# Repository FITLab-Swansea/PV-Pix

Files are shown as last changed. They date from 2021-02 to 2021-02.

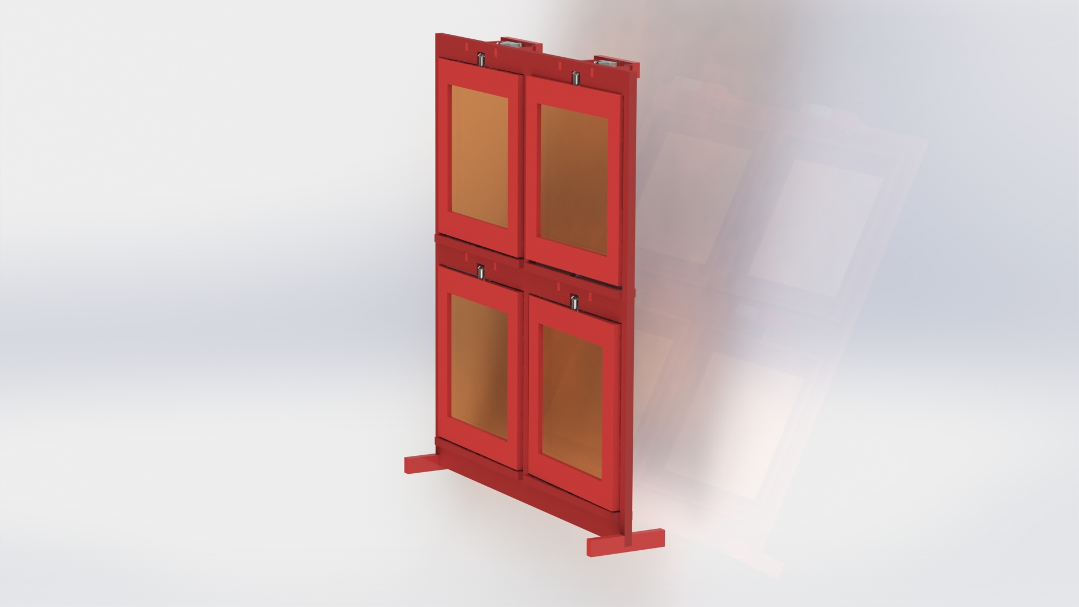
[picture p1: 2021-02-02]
CAD design/Tilttile Prototype/2x2 tilttile close.JPG

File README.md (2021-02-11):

# PV-Pix:
PV-Pix is a slum community co-design of self-powered deformable smart messaging materials for inter-home connections. Each PV-Pix element consists of a deformable energy harvesting material that, when actuated by a person in one home, changes its physical state both there and in a connected home. PV-Pix includes two forms of prototypes one uses rigid materials (TiltTile) and the other flexible ones (FabricOn). 

See the [toolkit website](https://deliot.me/toolkit.html) and [research project website](https://deliot.me) for more details and related work.

## Getting Started
By using the following step-by-step process you can build your own PV-Pix or you can reproduce our work. 

*Dye Sensitised Solar Cell (DSSC) fabrication

*Hardware design

*CAD design

*Bill of materials

*Software code

## License

This project is licensed under the MIT License - see the [LICENSE](LICENSE) and file for details.

The PV-Pix fabrication guide, electronics, prototype designs, MSP430FR5969 Ultra-Low-Power Microcontroller code, Arduino code are all released. 

## Acknowledgments

* FitLab
* Specific
* Swansea University
* EPSRC

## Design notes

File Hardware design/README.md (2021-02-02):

# PV-Pix 

*Hardware design 

It includes block diagram and servo modification process.  

Servo motor modification steps: 

1) Modify SG90 servo motor for continuous rotation. 

2) Remove gear that drives potentiometer.

3) Snip off a few mm of drive shaft. 

4) Trim off lugs. 

5) Set potentiometer to neutral position.

6) Reassemble. 

7) Test.

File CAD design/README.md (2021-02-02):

# PV-Pix 

*CAD design 

Here you can find all designs of both FabricOn and Tilttile prototypes. SolidWorks is used to create solid modeling computer-aided design (CAD). This folder includes both CAD files and images of both prototypes.

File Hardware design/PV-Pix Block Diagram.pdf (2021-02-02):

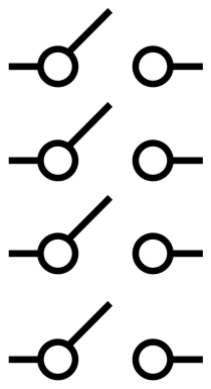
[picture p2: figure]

### MSP430F5529

### SERVO 1

### SERVO 2

### SERVO 3

### SERVO 4

### XBee S1

P2_6

P2_3

P1_6

P2_7

SW1

SW2

SW3

SW4

P8_1

P3_4

P3_3

TX

RX

En

# Transmitting 2x2 PV-Pix

P2_5 | P2_4
P1_5 | P1_4

P1_4

P1_5

P2_4

P2_5

### MSP430F5529

### SERVO 1

### SERVO 2

### SERVO 3

### SERVO 4

### XBee S1

P2_7

P3_4

P3_3

TX

RX

En

# Receiving 2x2 PV-Pix

P2_5 | P2_4
P1_5 | P1_4

P2_0

P1_5

P2_4

P2_5

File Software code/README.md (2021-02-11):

# PV-Pix 

*Software code: 
To create working prototypes use code scripts.

To make a working demo of TiltTile: 
Download the code script of TiltTile_2x2_RX.ino (Receive) and TiltTile_2x2_TX.ino (Transmit).
Upload this code script to microcontroller.
Create a demonstrator as seen in the PV-Pix video (https://deliot.me/toolkit.html)

To make a working demo of FabricOn: 
Download the code script of FabricOn.ino.
Upload this code script to microcontroller.
Create a demonstrator as seen in the PV-Pix video (https://deliot.me/toolkit.html)

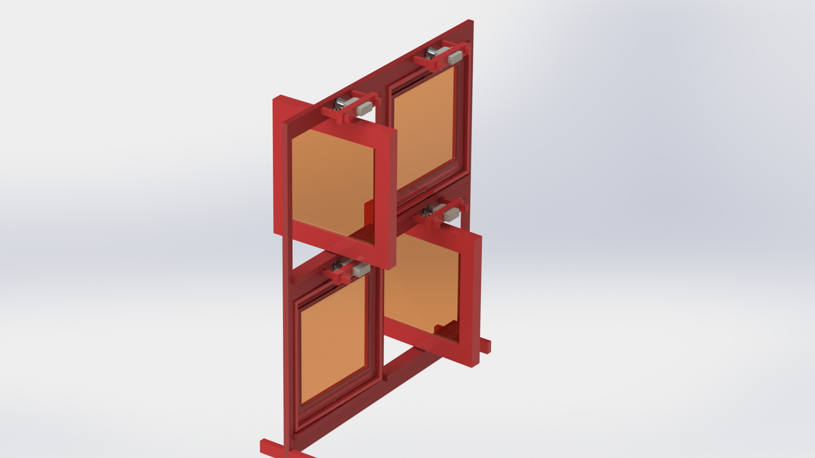
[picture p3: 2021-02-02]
CAD design/Tilttile Prototype/2x2 tilttile open.JPG

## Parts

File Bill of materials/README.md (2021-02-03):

# PV-Pix 

*bill of materials 

BoM document inlcudes parts, their quantity and suppliers for fabrication and construction of prototypes.

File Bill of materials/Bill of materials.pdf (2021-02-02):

PV-Pix was designed by: | and funded by:

PV-Pix: bill of materials

Parts for DSSC Fabrication

Part | Quantity | Supplier
RS PRO 16 Teeth Mitre Gear, 0.5mm Pitch, 20° Angle, 3mm Bore RS Stock No. 182-7986 | 16 | RS Components
Hitec HS40 Servo | 8 | modelshopleeds.co.uk
3mmPlain Miniature Ball Bearing 10mm O.D 618-9884 | 8 | RS Components
Burgundy acrylic 5 mm thick & 3 mm thick | - sheetplastics.co.uk
MSP-EXP430F5529LP | 2 | Digikey

Parts for PVPix Construction

Part | Quantity | Supplier
SG90 Servo motor | 1 | PI Hut
Burgundy acrylic 5 mm thick & 3 mm thick | - sheetplastics.co.uk
Arduino UNO | 1 | PI Hut
OPV Tape | 1 | infinitypv.com

Parts for FabricOn Construction

Part | Quantity | Supplier
FTO glass TEC 15A 2.1 mm x 30 mm x 30 mm | 3 | XOP FÍSICA SL
Ti Nanooxide T/SP | 50 g | Solaronix
Platisol T | 20 ml | Solaronix
Iodolyte Z-50 | 20 ml | Solaronix
Meltonix 1170-60 | 30 cm x 20 cm | Solaronix
Screen MCI 245 mesh 43-80, 45 deg, 13m EXP | 1 | MCI Precision Screen

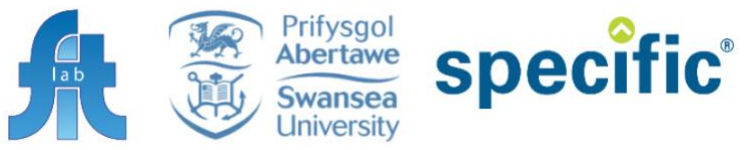
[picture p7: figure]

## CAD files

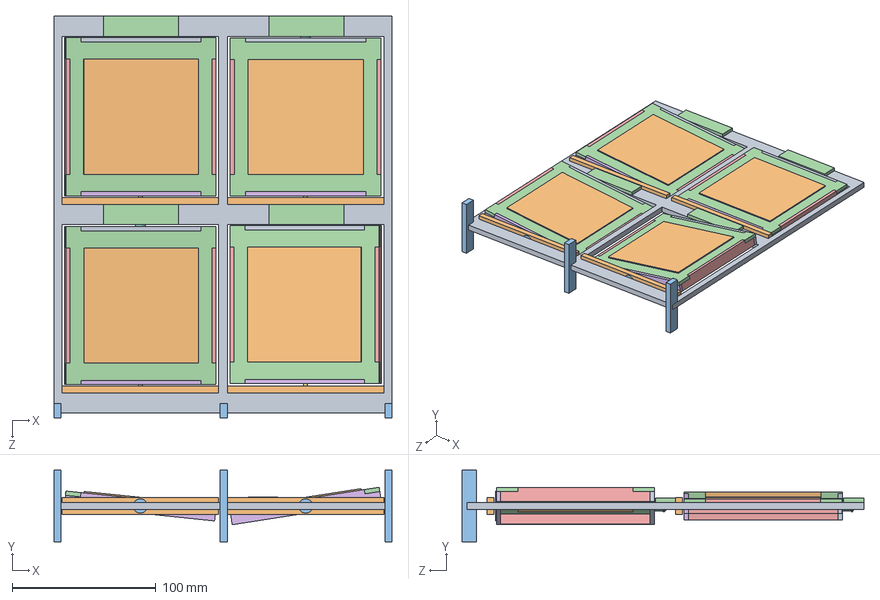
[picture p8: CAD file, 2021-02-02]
CAD design/Tilttile Prototype/Assembly_of_2x2.SLDASM
235.0 x 50.0 x 279.2 mm
Outer_Frame
Bearing_Holder2x2 x 4
Bearign x 4
LeftMount x 4
Side_Frame x 8
Top_and_Bottom_Frame x 4
Dowel x 8
straight bevel pinion_iso x 4
Top_with_hole x 4
Coloured_Glass x 4
Legs x 3
cover x 4

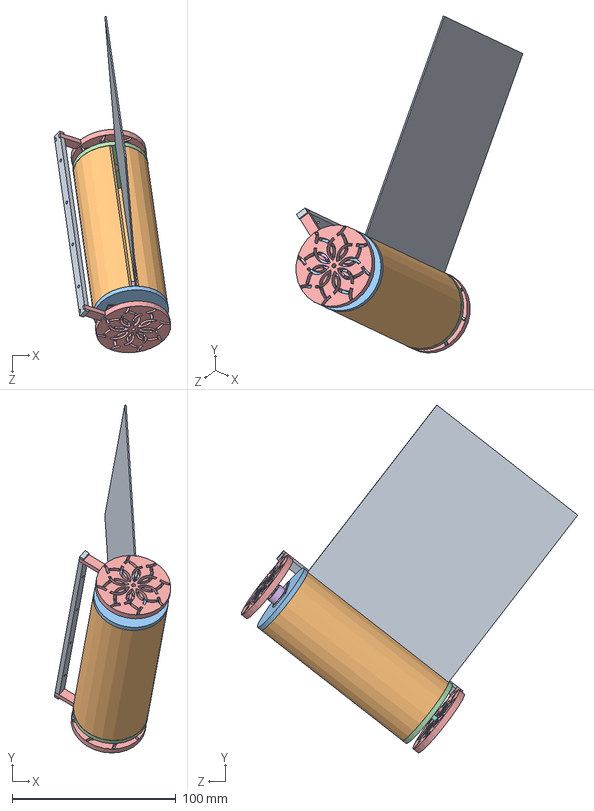
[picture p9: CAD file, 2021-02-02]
CAD design/FabricOn Prototype/Assem_Of_Prototype1.SLDASM
71.2 x 212.7 x 205.7 mm
Back_Plate
Hollow_Roller
Hollow_Roller_Servo_Side
Bearing_Hollow
Final_Bearing_Side x 2
sg90
Fat_Bearing
Dowel

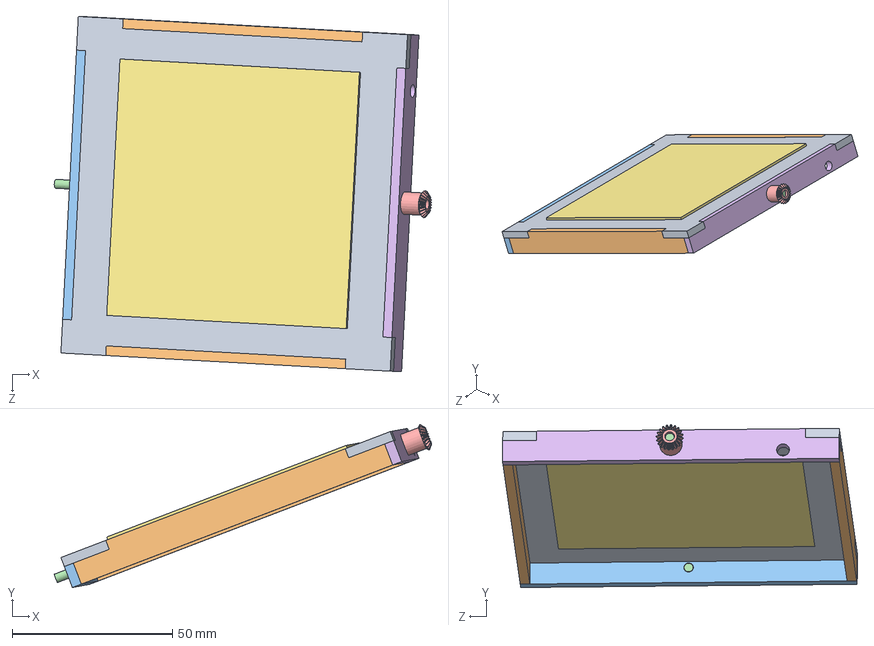
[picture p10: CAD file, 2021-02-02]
CAD design/Tilttile Prototype/Frame_And_Tile.SLDASM
117.6 x 50.8 x 110.6 mm
LeftMount
Side_Frame x 2
Top_and_Bottom_Frame
Dowel x 2
straight bevel pinion_iso
Top_with_hole
Coloured_Glass

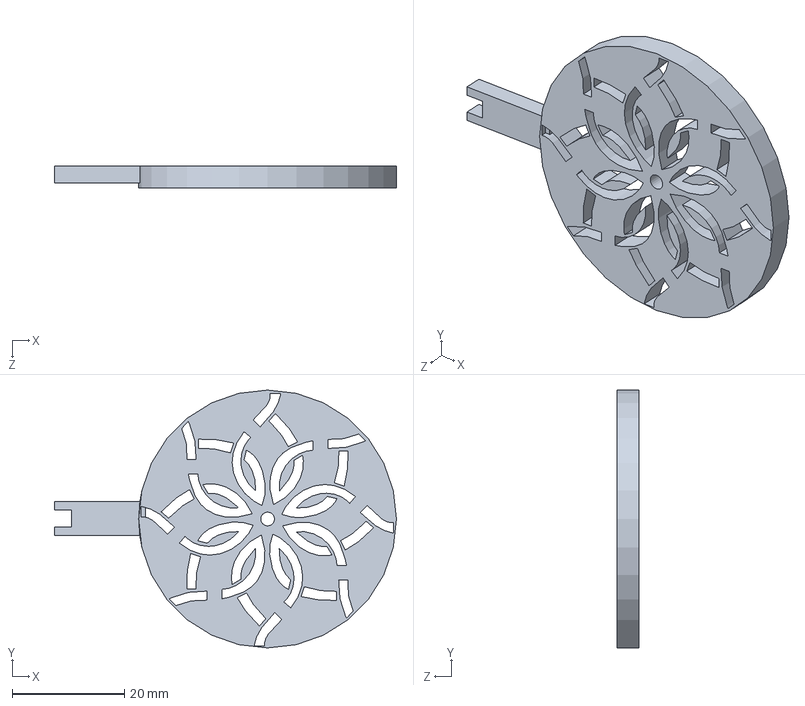
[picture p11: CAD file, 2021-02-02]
CAD design/FabricOn Prototype/Final_Bearing_Side.SLDPRT
61.0 x 46.0 x 3.94 mm

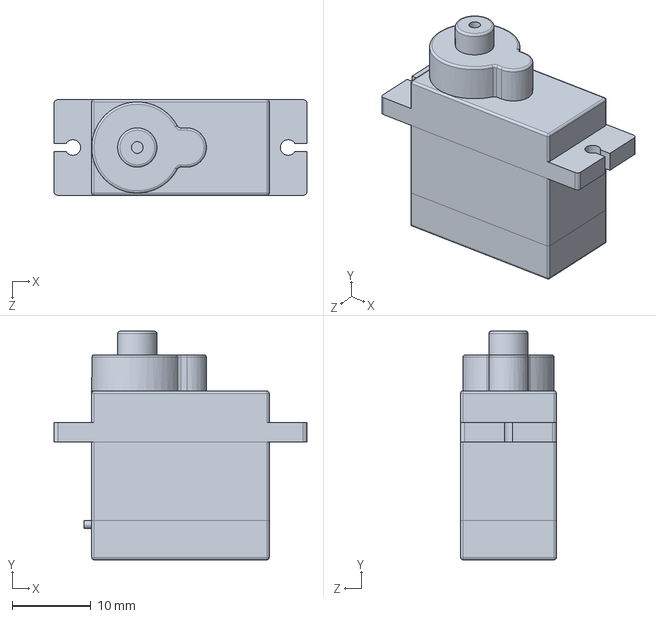
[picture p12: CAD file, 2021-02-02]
CAD design/FabricOn Prototype/sg90.SLDPRT
32.2 x 29.1 x 12.2 mm

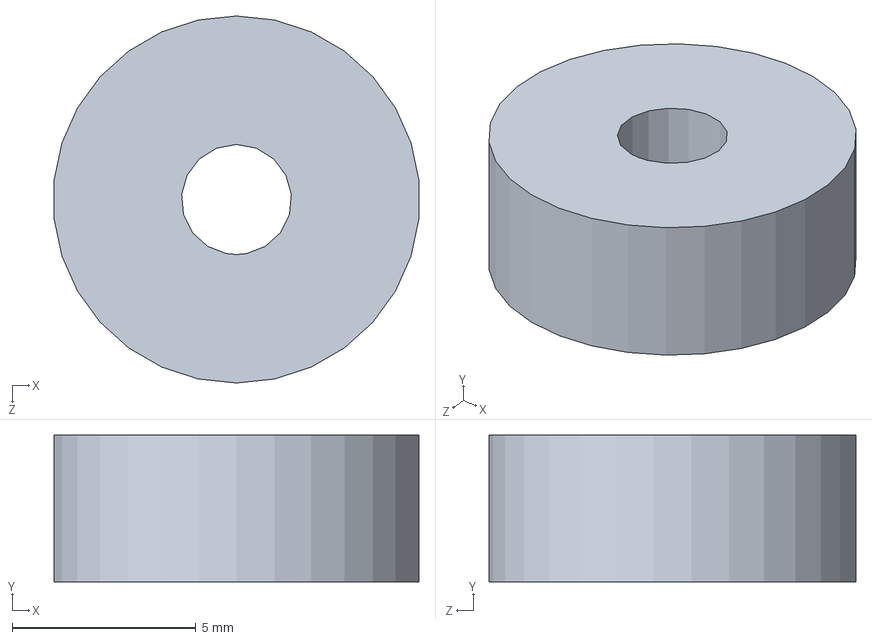
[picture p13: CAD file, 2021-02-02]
CAD design/Tilttile Prototype/Bearign.SLDPRT
9.95 x 4.00 x 10.0 mm

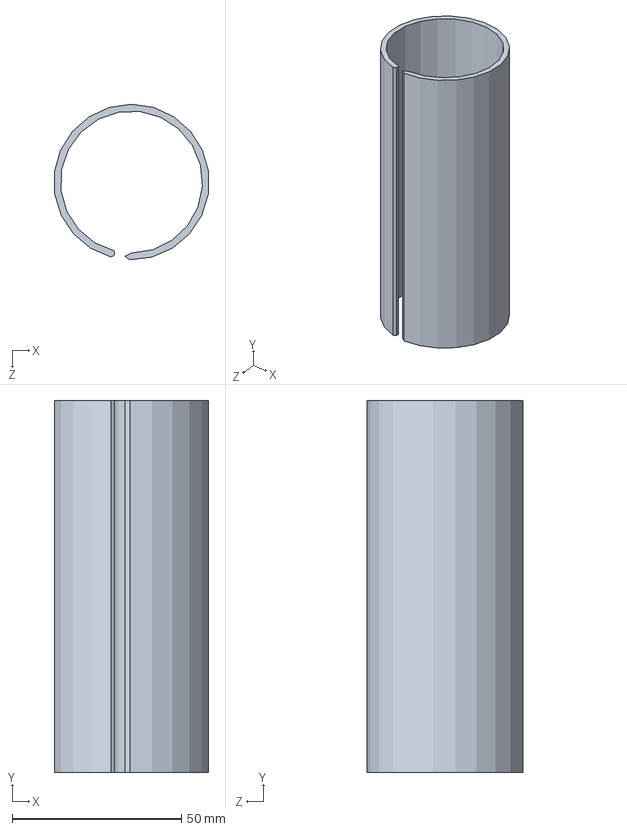
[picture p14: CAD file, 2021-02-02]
CAD design/FabricOn Prototype/Hollow_Roller.SLDPRT
45.6 x 110.0 x 46.0 mm

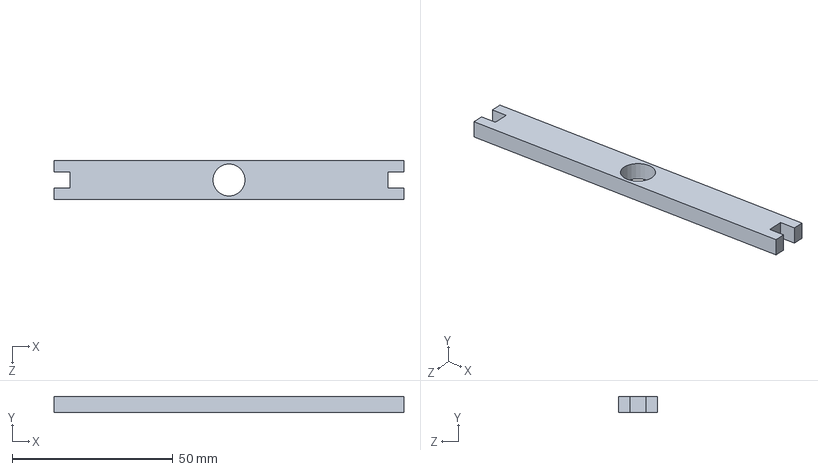
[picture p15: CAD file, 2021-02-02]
CAD design/Tilttile Prototype/Bearing_Holder2x2.SLDPRT
109.0 x 5.00 x 12.0 mm

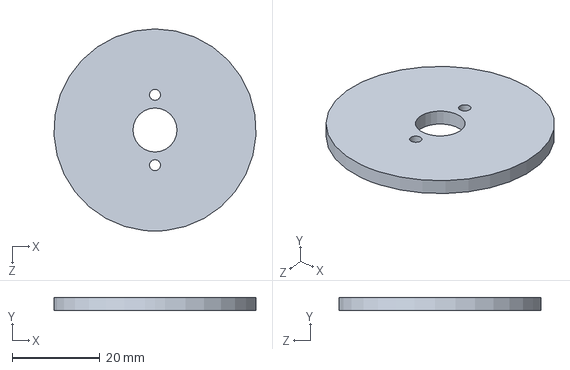
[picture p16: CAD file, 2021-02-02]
CAD design/FabricOn Prototype/Bearing_Hollow.SLDPRT
45.9 x 3.00 x 46.0 mm

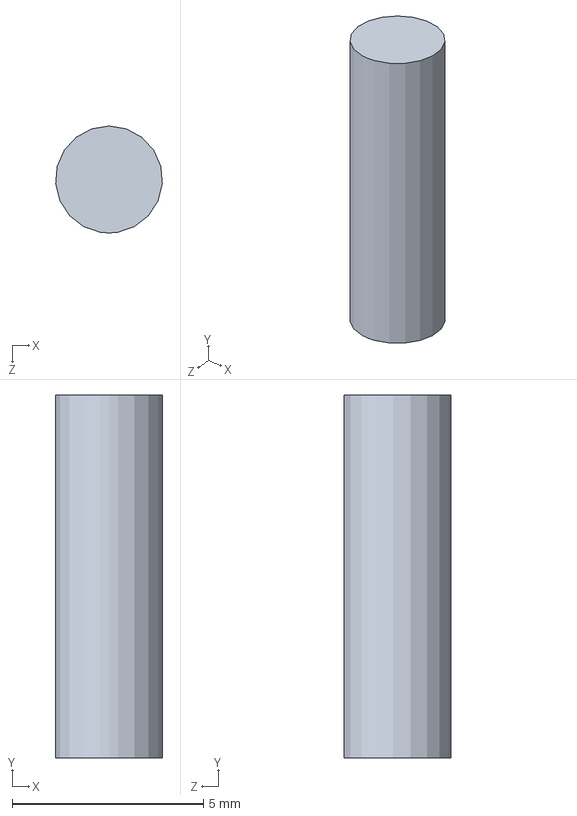
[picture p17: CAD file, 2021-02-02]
CAD design/Tilttile Prototype/Dowel.SLDPRT
2.79 x 9.50 x 2.80 mm

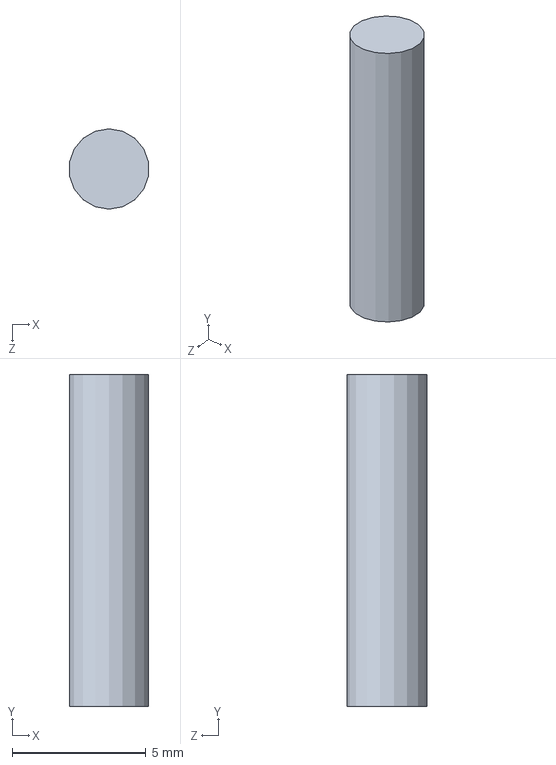
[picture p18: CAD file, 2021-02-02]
CAD design/FabricOn Prototype/Dowel.SLDPRT
2.95 x 12.4 x 3.00 mm

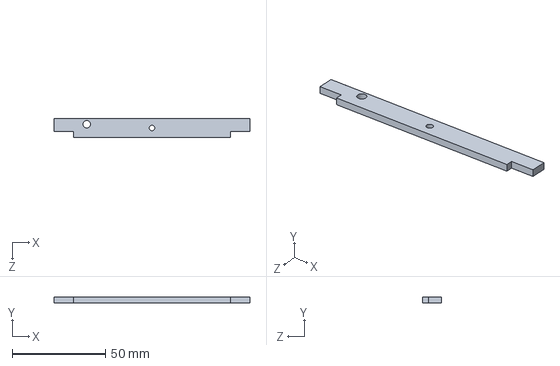
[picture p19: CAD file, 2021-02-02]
CAD design/Tilttile Prototype/Top_with_hole.SLDPRT
105.0 x 3.00 x 10.0 mm

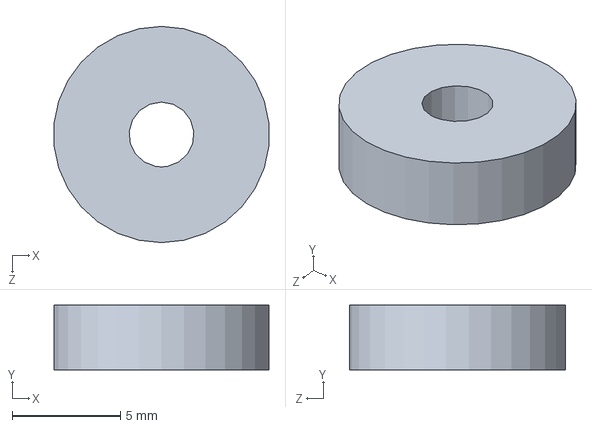
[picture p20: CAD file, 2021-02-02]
CAD design/FabricOn Prototype/Fat_Bearing.SLDPRT
9.95 x 3.00 x 10.0 mm

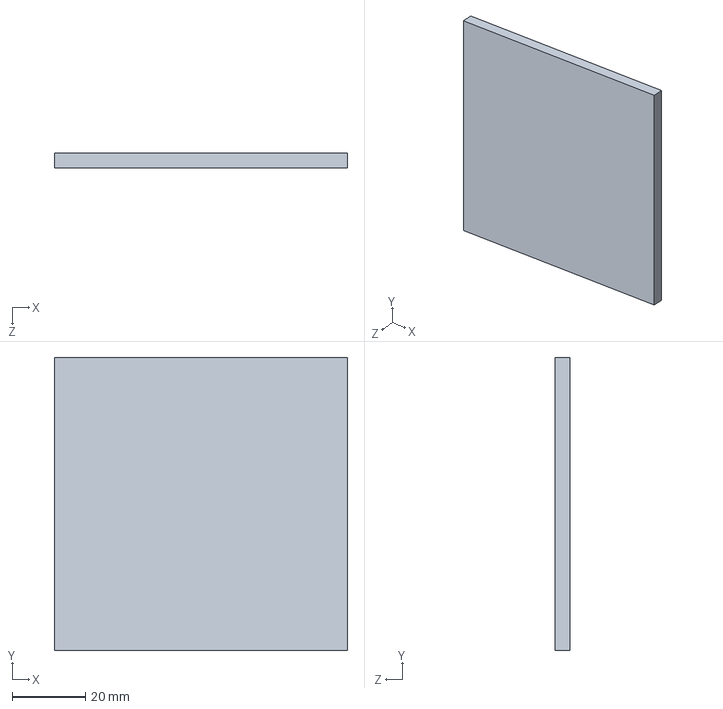
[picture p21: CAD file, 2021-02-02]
CAD design/Tilttile Prototype/Coloured_Glass.SLDPRT
80.0 x 80.0 x 4.00 mm

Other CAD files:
CAD design/FabricOn Prototype/OPV_FLAT.SLDPRT
CAD design/Tilttile Prototype/Side_Frame.SLDPRT
CAD design/Tilttile Prototype/Legs.SLDPRT
CAD design/FabricOn Prototype/Hollow_Roller_Servo_Side.SLDPRT
CAD design/FabricOn Prototype/Back_Plate.SLDPRT
CAD design/Tilttile Prototype/LeftMount.SLDPRT
CAD design/Tilttile Prototype/Outer_Frame.SLDPRT
CAD design/Tilttile Prototype/Top_and_Bottom_Frame.SLDPRT
CAD design/Tilttile Prototype/cover.SLDPRT

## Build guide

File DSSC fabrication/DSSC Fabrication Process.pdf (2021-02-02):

PV-Pix was designed by: | and funded by:

Dye Sensitised Solar Cell (DSSC) fabrication process:

- Fluorine doped Tin Oxide (FTO) coated glass substrates are washed with detergent (Helmanex 5% in DI water) and sonicated for 15 minutes, rinsed in DI water, and followed by 2 minutes sonication in each of DI water, Acetone, and Isopropyl alcohol before drying in N2 stream.
- Substrates were then plasma cleaned for 10 minutes in an O2 plasma to remove any organic material and improve wettability.
- A nano-porous titania layer is deposited on the FTO by screen printing or doctor-blading before sintering in an oven or hotplate at 450 degrees centigrade. The sintered nano-porous titania is then dyed by over-night emersion in ruthenium dye (Ruthenizer 535-bis TBA from Solaronix) solution.
- Excess dye is rinsed off with ethanol before the substrate is dried in a N2 stream.
- The top plate has filling holes drilled before the plate is cleaned, as above, in preparation for quasi-transparent layer of activated platinum deposition Platisol T (Solaronix) by spin coating. The top plate is then dried on a hot plate.
- In the final stages of DSSC fabrication, a sealing gasket laser cut from 60 µm thick thermoplastic Surlyn® is sandwiched between the two plates and pressed together at ~120 degrees centigrade for 30 seconds. The cavity formed between the top plate and dyesensitized substrate is filled with iodide/tri-iodide electrolyte by capillary action before the filling holes are sealed.


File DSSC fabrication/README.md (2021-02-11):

# PV-Pix 

*DSSC fabrication

Step by step process is explained in the pdf file.
We produced video to tech community about solar cells. It include the step-by-step process of fabricating a DSSC.

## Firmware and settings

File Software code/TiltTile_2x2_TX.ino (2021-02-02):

//TiltTile 2x2 TX Demo

#include <Servo.h> 
 
Servo myservo1;  // Create servo object to control a servo a maximum of eight servo objects can be created 
Servo myservo2;  
Servo myservo3;
Servo myservo4;

int tile1_open_closed = 0; //'HIGH' open; 'LOW' closed
int tile2_open_closed = 0;
int tile3_open_closed = 0;
int tile4_open_closed = 0;

volatile int tile1_touched = 0;     //Has tile been touched?
volatile int tile2_touched = 0;
volatile int tile3_touched = 0;
volatile int tile4_touched = 0;

 
void setup() 
{ 
  pinMode(P8_1, OUTPUT); // XBee enable (LOW)
  pinMode(P3_4, OUTPUT); // UART RX
  pinMode(P3_3, OUTPUT); // UART TX

  pinMode(P2_2, OUTPUT); //Enable Servos

  pinMode(P2_6, INPUT_PULLUP); //Touch pins
  pinMode(P2_3, INPUT_PULLUP);
  pinMode(P1_6, INPUT_PULLUP);
  pinMode(P2_7, INPUT_PULLUP); 

  //Attach interrupt
  attachInterrupt(digitalPinToInterrupt (P2_6), tilt_tile1, RISING);
  attachInterrupt(digitalPinToInterrupt (P2_3), tilt_tile2, RISING);
  attachInterrupt(digitalPinToInterrupt (P1_6), tilt_tile3, RISING);
  attachInterrupt(digitalPinToInterrupt (P2_7), tilt_tile4, RISING);  

  Serial.begin(9600);       //Debug
  Serial1.begin(9600);

  myservo1.attach(P2_5);
  myservo2.attach(P2_4); 
  myservo3.attach(P1_5);
  myservo4.attach(P1_4);

    Serial.print("Setup ");
            
} 
 
void loop() 
{ 
 
 Serial.println("loop");

  if(tile1_touched == '1'){                  /******** Tile 1 ********/
    digitalWrite(P2_2, HIGH);             //Enable Servos          
      if(tile1_open_closed == '0'){           //Toggle tile position. LOW = closed
        tile1_open_closed = '1';
        myservo1.write(90);                  //Move tile to open position
        digitalWrite(P2_7, LOW);               //Enable XBee
        Serial1.print('1');                   //Transmit ASCII '1'
        //Serial1.print('5');                   //Transmit ASCII '5' for open
        digitalWrite(P2_7, HIGH);              //Disable XBee
      }else{                                  //HIGH = open
        tile1_open_closed = '0';
        myservo1.write(0);                  //Move tile to open position
        digitalWrite(P2_7,LOW);               //Enable XBee
        Serial1.print('2');                   //Transmit ASCII '1'
        //Serial1.print('6');                   //Transmit ASCII '6' for closed
        digitalWrite(P2_7,HIGH);              //Disable XBee
      }
    
  }else if(tile2_touched == '1'){            /******** Tile 2 ********/ 
    digitalWrite(P2_2, HIGH);             //Enable Servos                                       
      if(tile2_open_closed == '0'){          
        tile2_open_closed = '1';
        myservo2.write(90);                  //Move tile to open position
        digitalWrite(P2_7,LOW);               //Enable XBee
        Serial1.print('3');                   //Transmit ASCII '2'
        //Serial1.print('5');                   //Transmit ASCII '5' for open
        digitalWrite(P2_7,HIGH);              //Disable XBee
      }else{                            
        tile2_open_closed = '0';
        myservo2.write(0);                  //Move tile to open position
        digitalWrite(P2_7,LOW);               //Enable XBee
        Serial1.print('4');                   //Transmit ASCII '2'
        //Serial1.print('6');                   //Transmit ASCII '6' for closed
        digitalWrite(P2_7,HIGH);              //Disable XBee 
      }
    
  }else if(tile3_touched == '1'){            /******** Tile 3 ********/  
    digitalWrite(P2_2, HIGH);             //Enable Servos                                       
      if(tile3_open_closed == '0'){          
        tile3_open_closed = '1';
        myservo3.write(90);                  //Move tile to open position
        digitalWrite(P2_7,LOW);               //Enable XBee
        Serial1.print('5');                   //Transmit ASCII '3'
        //Serial1.print('5');                   //Transmit ASCII '5' for open
        digitalWrite(P2_7,HIGH);              //Disable XBee
      }else{                                
        tile3_open_closed = '0'; 
        myservo3.write(0);                  //Move tile to open position
        digitalWrite(P2_7,LOW);               //Enable XBee
        Serial1.print('6');                   //Transmit ASCII '3'
        //Serial1.print('6');                   //Transmit ASCII '6' for closed
        digitalWrite(P2_7,HIGH);              //Disable XBee 
      }
      
  }else if(tile4_touched == '1'){            /******** Tile 4 ********/ 
    digitalWrite(P2_2, HIGH);             //Enable Servos                               
      if(tile4_open_closed == '0'){          
         tile4_open_closed = '1';
         myservo4.write(90);                  //Move tile to open position
         digitalWrite(P2_7,LOW);               //Enable XBee
         Serial1.print('7');                   //Transmit ASCII '4'
         //Serial1.print('5');                   //Transmit ASCII '5' for open
         digitalWrite(P2_7,HIGH);              //Disable XBee
      }else{                                
         tile4_open_closed = '0'; 
         myservo4.write(0);                  //Move tile to open position
         digitalWrite(P2_7,LOW);               //Enable XBee
         Serial1.print('8');                   //Transmit ASCII '4'
         //Serial1.print('6');                   //Transmit ASCII '6' for closed
         digitalWrite(P2_7,HIGH);              //Disable XBee 
  
      }
      
  }else{
     //Do nothing
  }
  

  delay(1500); 
  digitalWrite(P2_2, LOW);              //Disable Servos  
  tile1_touched = '0';         //Reset all tiles to untouched
  tile2_touched = '0';
  tile3_touched = '0';
  tile4_touched = '0';
  
  suspend();                   //MCU to low power mode

  
}

/*********** Interrupt Service Routines ***********/

void tilt_tile1(){
  tile1_touched = '1';
  wakeup(); 
}

void tilt_tile2(){
  tile2_touched = '1';
  wakeup();
}

void tilt_tile3(){
  tile3_touched = '1';
  wakeup();
}

void tilt_tile4(){      //tilt_tile4
  tile4_touched = '1';
  wakeup();
}

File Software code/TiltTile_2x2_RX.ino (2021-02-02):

//TiltTile 2x2 RX Demo

/*Continually watches for characters from 2x2 TX demo*/


#include <Servo.h> 
 
Servo myservo1;  // create servo object to control a servo a maximum of eight servo objects can be created 
Servo myservo2;  
Servo myservo3;
Servo myservo4;

int byte_one;
int byte_two;
//char next_byte;
 
void setup() 
{ 
  pinMode(P2_7, OUTPUT); // XBee enable (LOW)
  pinMode(P3_4, OUTPUT); // UART RX
  pinMode(P3_3, OUTPUT); // UART TX

  digitalWrite(P2_2, LOW); //Permanently enabled XBee


  Serial.begin(9600);  //for debugging
  Serial1.begin(9600);

  pinMode(P2_5, OUTPUT); 
  pinMode(P2_4, OUTPUT);
  pinMode(P1_5, OUTPUT);
  pinMode(P2_0, OUTPUT);
  
  myservo1.attach(P2_5);
  myservo2.attach(P2_4); 
  myservo3.attach(P1_5);
  myservo4.attach(P2_0);
} 


 
void loop() 
{ 
  /*Continually poll for new characters*/

  if (Serial1.available() > 0){               //Character available 
      byte_one = Serial1.read();
      //byte_two = Serial1.read();
      Serial.print(byte_one);
      //Serial.print(byte_two);


    if (byte_one == '1'){                      
        Serial.println("Servo1 Open"); 
        myservo1.write(90);                
        delay(1500);
    }else if (byte_one == '2'){
      Serial.println("Servo1 Closed");
        myservo1.write(0);                    
        delay(1500);
    }else if(byte_one == '3'){   
        Serial.println("Servo2 Open");      
        myservo2.write(90);   
        delay(1500);                 
    }else if (byte_one == '4'){          
        myservo2.write(0);  
        Serial.println("Servo2 Closed");
        delay(1500);                              
    }else if (byte_one == '5'){                
        Serial.println("Servo3 Open");          
        myservo3.write(90);
        delay(1500);                              
     }else if (byte_one == '6'){            
        Serial.println("Servo3 Closed");
        myservo3.write(0);  
        delay(1500);                 
     }else if (byte_one == '7'){           
        Serial.println("Servo4 Open");          
        myservo4.write(90);  
        delay(1500);                             
     }else if (byte_one == '8'){          
        Serial.println("Servo4 Closed");  
        myservo4.write(0);   
        delay(1500);                              
     }else{
      //Do nothing
     }
  }
}
